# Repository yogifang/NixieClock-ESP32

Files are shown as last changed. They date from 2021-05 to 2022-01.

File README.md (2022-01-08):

# NixieClock-ESP32
Build a Clock with  Nixie Tubes 
1. MCU : ESP32-32D
2. System : Arduino 
3. Development tools : Visual Studio Code + PlatformIO + Kicad
4. Functions : Webpage Setting Wifi SSID , password & Time Zone , NTP client sync time once every day.
Watch the video

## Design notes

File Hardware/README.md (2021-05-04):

Download whole directory.
Open Project in Kicad (Ver 5.1.2-1).
ESP32-Clock is main board for 6 digits of Nixie Tubes.
Nixie is for IN-18.

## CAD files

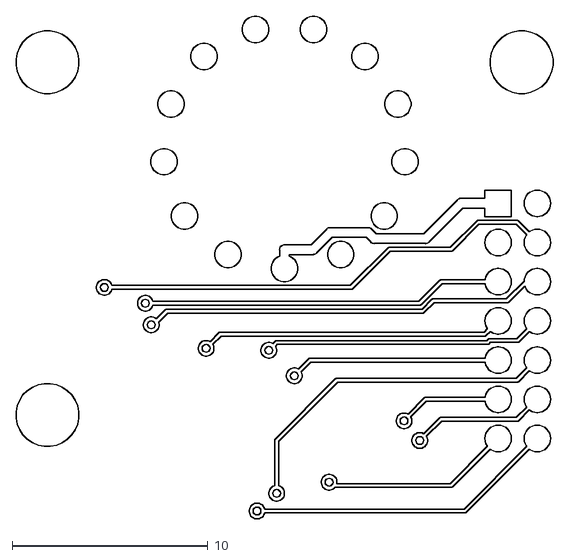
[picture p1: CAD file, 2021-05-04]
Hardware/Nixie/Nixie-B_Cu.dxf
27.4 x 25.6

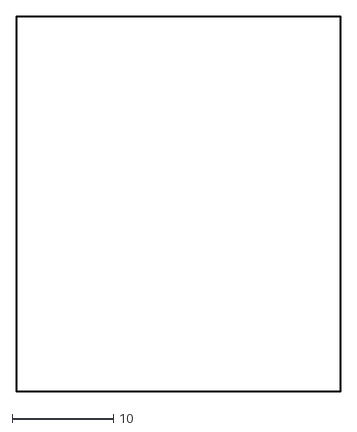
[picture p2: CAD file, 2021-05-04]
Hardware/Nixie/Nixie-Edge_Cuts.dxf
32.1 x 37.1

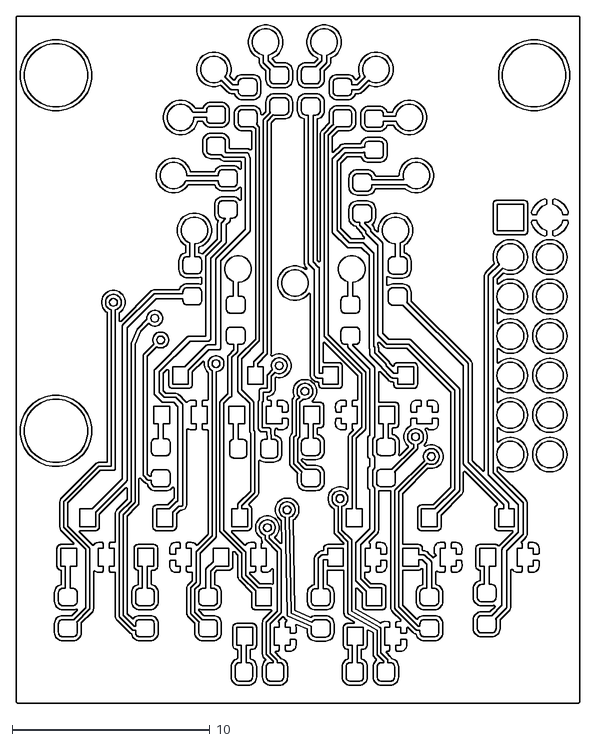
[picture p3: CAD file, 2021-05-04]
Hardware/Nixie/Nixie-F_Cu.dxf
28.5 x 34.8

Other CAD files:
Hardware/Nixie/Nixie-B_Mask.dxf
Hardware/Nixie/Nixie-B_Paste.dxf
Hardware/Nixie/Nixie-F_Mask.dxf
Hardware/Nixie/Nixie-F_Paste.dxf
Hardware/Nixie/Nixie-F_SilkS.dxf

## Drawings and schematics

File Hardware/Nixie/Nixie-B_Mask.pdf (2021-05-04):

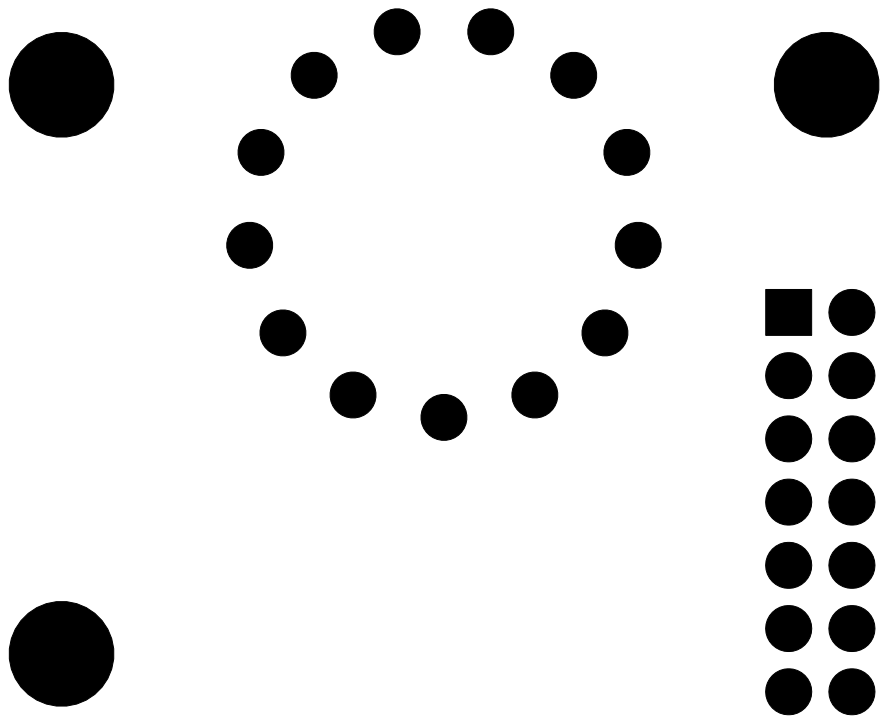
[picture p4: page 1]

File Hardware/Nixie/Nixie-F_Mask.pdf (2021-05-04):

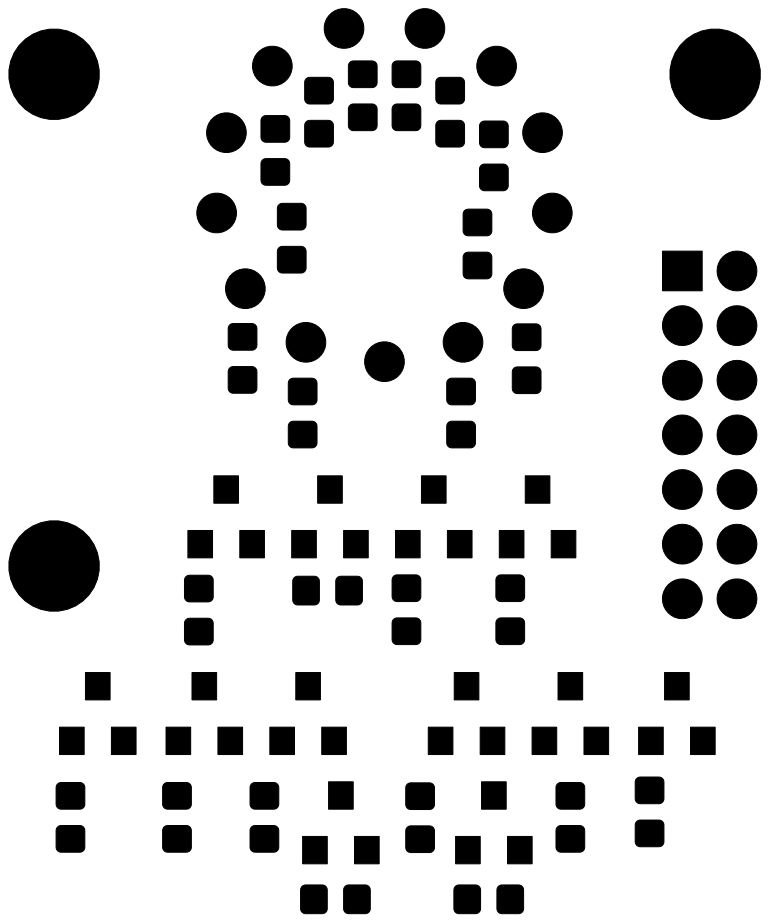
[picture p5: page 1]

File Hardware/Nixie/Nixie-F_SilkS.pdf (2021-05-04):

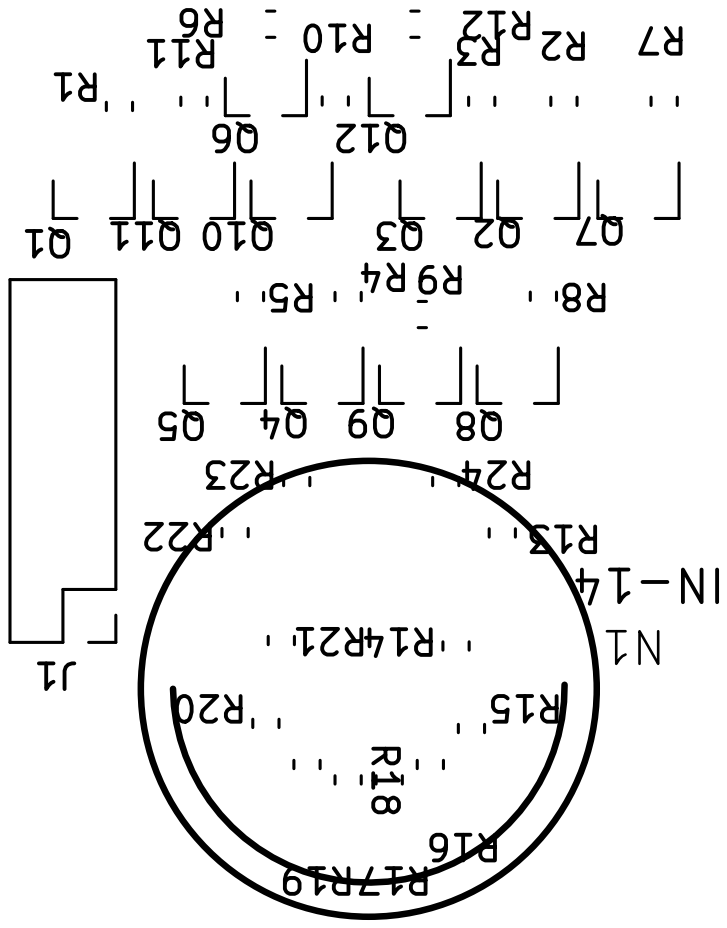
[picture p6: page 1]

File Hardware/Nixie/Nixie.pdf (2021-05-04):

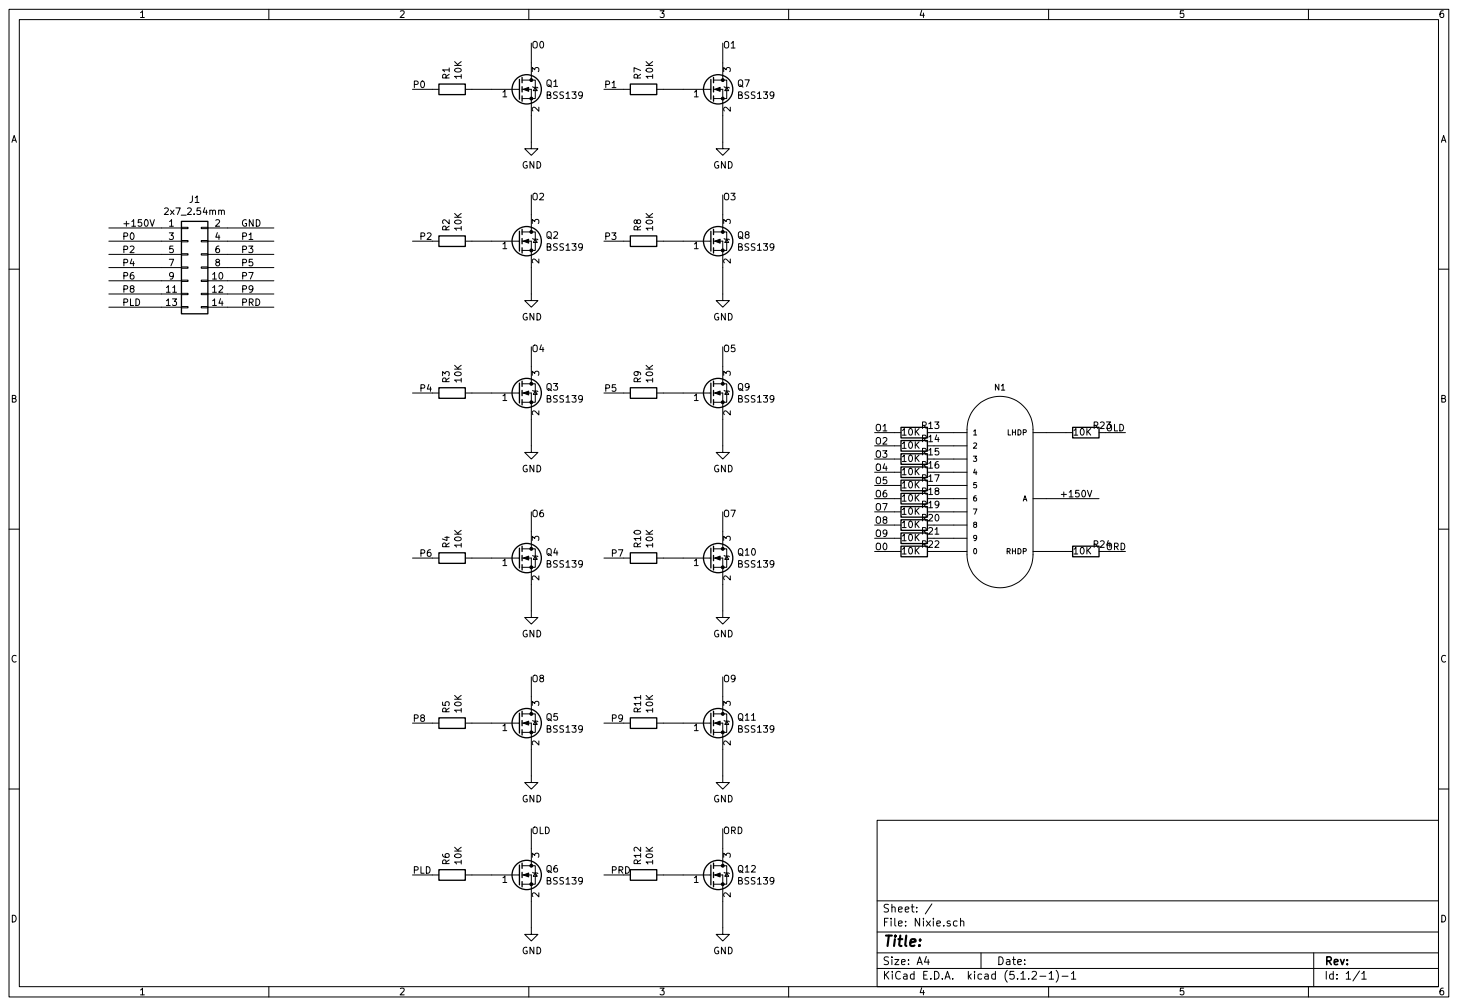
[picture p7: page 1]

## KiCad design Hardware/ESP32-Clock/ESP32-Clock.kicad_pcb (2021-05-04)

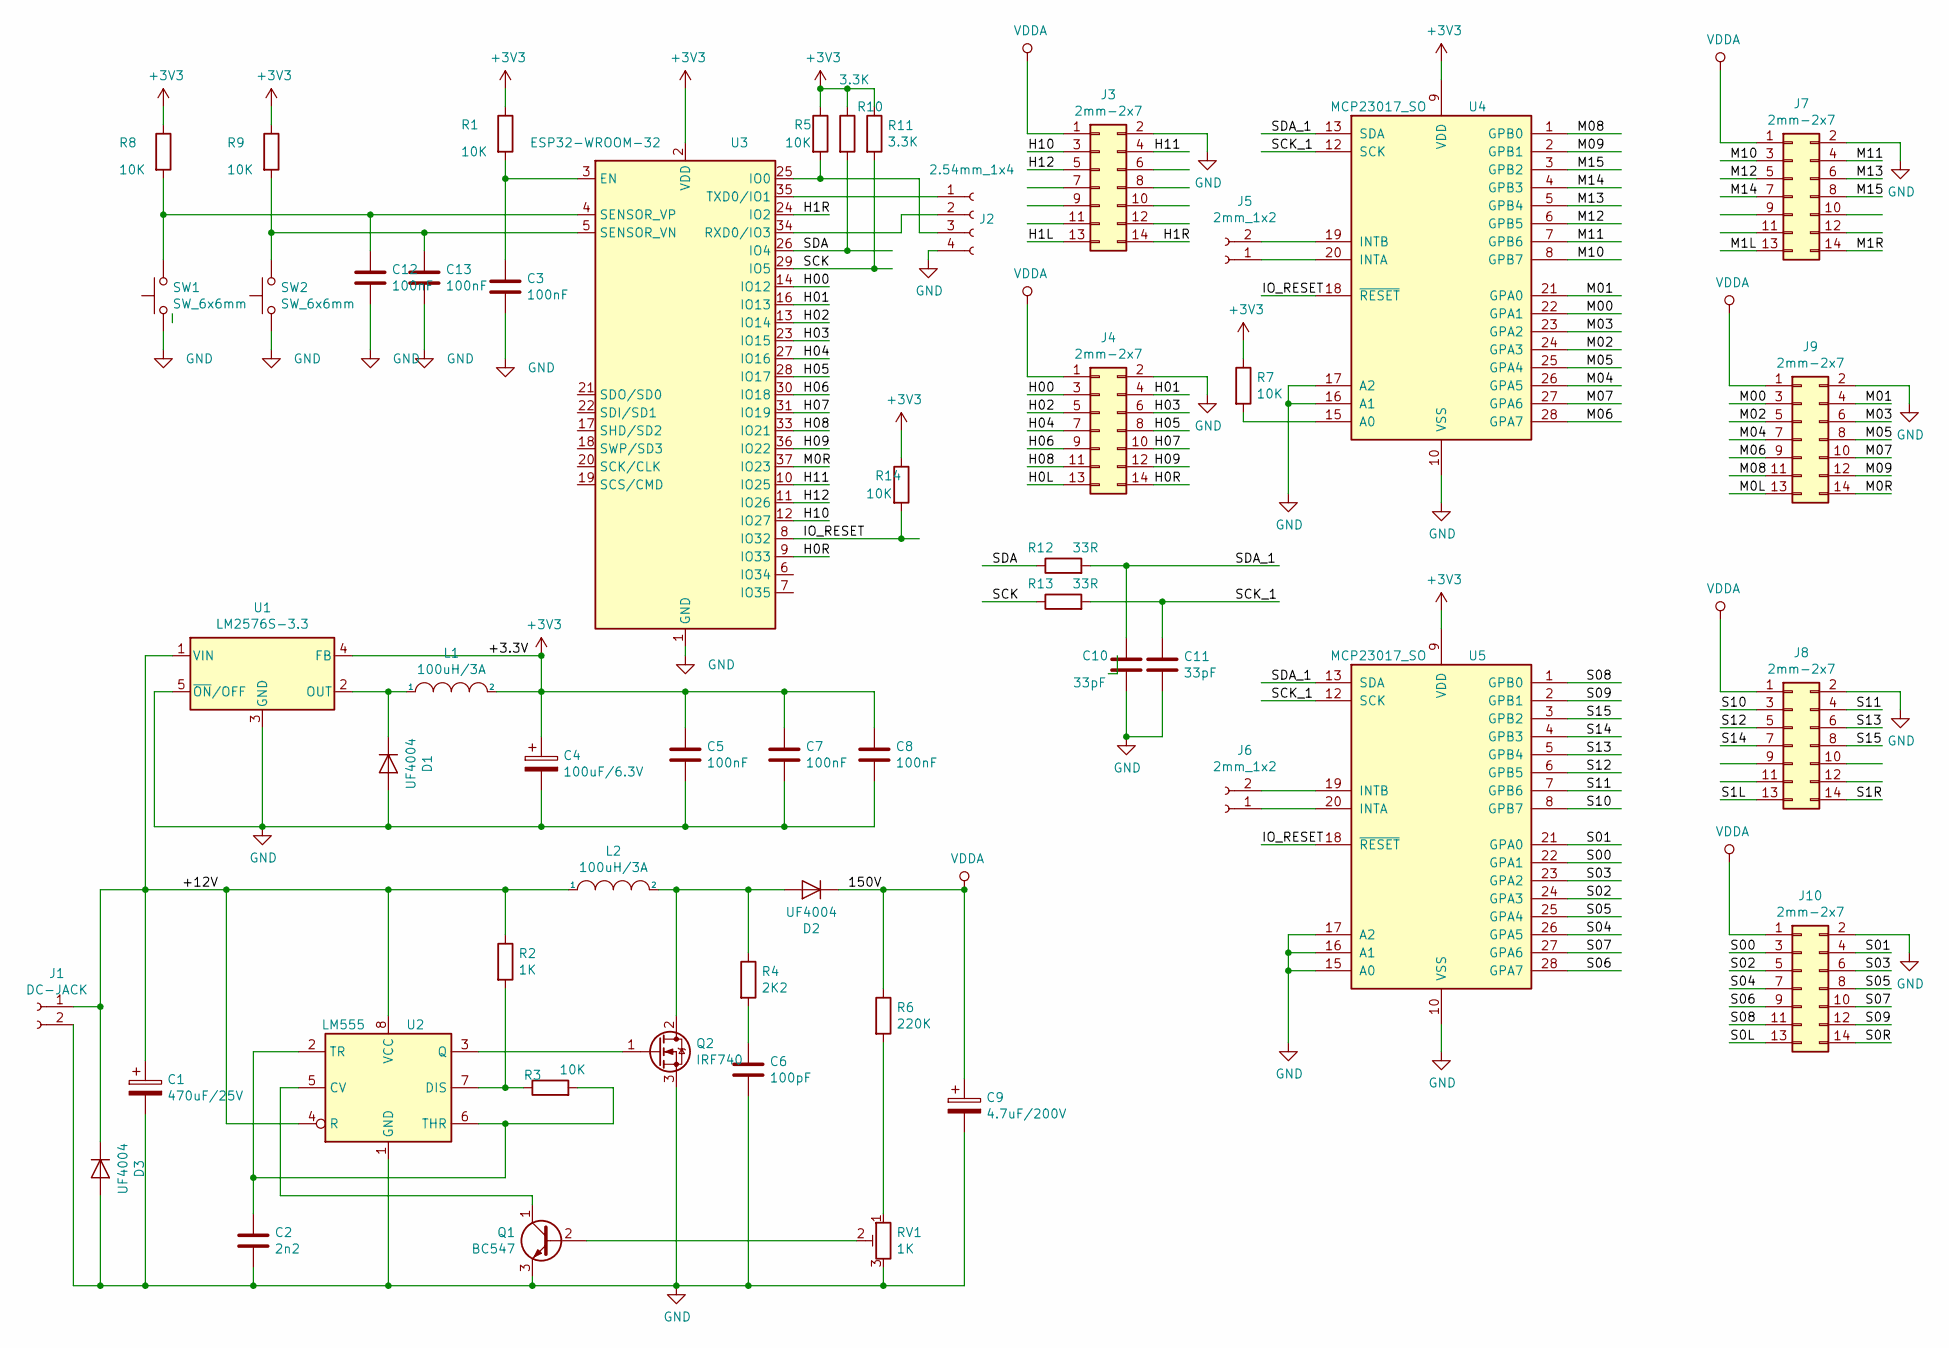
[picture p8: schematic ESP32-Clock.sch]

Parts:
C1: 470uF/25V; CP_Elec_10x10
C2: 2n2; C_0603_1608Metric
C3, C5, C7, C8, C12, C13: 100nF; C_0603_1608Metric
C4: 100uF/6.3V; CP_Elec_6.3x5.9
C6: 100pF; C_0603_1608Metric
C9: 4.7uF/200V; C_Radial_D8.0mm_H11.5mm_P3.50mm
C10, C11: 33pF; C_0603_1608Metric
D1, D2, D3: UF4004; D_SMA
J1: DC-JACK; BarrelJack_Horizontal
J2: 2.54mm_1x4; PinHeader_1x04_P2.54mm_Vertical
J3, J4, J7, J8, J9, J10: 2mm-2x7; PinHeader_2x07_P2.00mm_Vertical
J5, J6: 2mm_1x2; PinSocket_1x02_P2.00mm_Vertical
L1, L2: 100uH/3A; L_Toroid_Vertical_L13.0mm_W6.5mm_P5.60mm
Q1: BC547; TO-92_Inline
Q2: IRF740; TO-263-2
R1, R3, R5, R7, R8, R9, R14: 10K; R_0603_1608Metric
R2: 1K; R_0603_1608Metric
R4: 2K2; R_0805_2012Metric
R6: 220K; R_0805_2012Metric
R10, R11: 3.3K; R_0603_1608Metric
R12, R13: 33R; R_0603_1608Metric
RV1: 1K; Potentiometer_Bourns_3386P_Vertical
SW1, SW2: SW_6x6mm; SW_SPST_B3S-1000
U1: LM2576S-3.3; TO-263-5_TabPin3
U2: LM555; SOIC-8-1EP_3.9x4.9mm_P1.27mm_EP2.29x3mm_ThermalVias
U3: ESP32-WROOM-32
U4, U5: MCP23017_SO; SOIC-28W_7.5x17.9mm_P1.27mm

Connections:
+3V3: C4.1, C5.1, C7.1, C8.1, L1.2, R1.1, R5.1, R7.1, R8.1, R9.1, R10.1, R11.1, R14.1, U1.4 (FB), U3.2 (VDD), U4.9 (VDD), U5.9 (VDD)
/+12V: C1.1, D3.1 (K), J1.1, L2.1, R2.1, U1.1 (VIN), U2.4 (R), U2.8 (VCC)
/H00: J4.3, U3.14 (IO12)
/H0L: J4.13
/H0R: J4.14, U3.9 (IO33)
/H01: J4.4, U3.16 (IO13)
/H1L: J3.13
/H1R: J3.14, U3.24 (IO2)
/H02: J4.5, U3.13 (IO14)
/H03: J4.6, U3.23 (IO15)
/H04: J4.7, U3.27 (IO16)
/H05: J4.8, U3.28 (IO17)
/H06: J4.9, U3.30 (IO18)
/H07: J4.10, U3.31 (IO19)
/H08: J4.11, U3.33 (IO21)
/H09: J4.12, U3.36 (IO22)
/H10: J3.3, U3.12 (IO27)
/H11: J3.4, U3.10 (IO25)
/H12: J3.5, U3.11 (IO26)
/IO_RESET: R14.2, U3.8 (IO32), U4.18 (~RESET~), U5.18 (~RESET~)
/M00: J9.3, U4.22 (GPA1)
/M0L: J9.13
/M0R: J9.14, U3.37 (IO23)
/M01: J9.4, U4.21 (GPA0)
/M1L: J7.13
/M1R: J7.14
/M02: J9.5, U4.24 (GPA3)
/M03: J9.6, U4.23 (GPA2)
/M04: J9.7, U4.26 (GPA5)
/M05: J9.8, U4.25 (GPA4)
/M06: J9.9, U4.28 (GPA7)
/M07: J9.10, U4.27 (GPA6)
/M08: J9.11, U4.1 (GPB0)
/M09: J9.12, U4.2 (GPB1)
/M10: J7.3, U4.8 (GPB7)
/M11: J7.4, U4.7 (GPB6)
/M12: J7.5, U4.6 (GPB5)
/M13: J7.6, U4.5 (GPB4)
/M14: J7.7, U4.4 (GPB3)
/M15: J7.8, U4.3 (GPB2)
/S00: J10.3, U5.22 (GPA1)
/S0L: J10.13
/S0R: J10.14
/S01: J10.4, U5.21 (GPA0)
/S1L: J8.13
/S1R: J8.14
/S02: J10.5, U5.24 (GPA3)
/S03: J10.6, U5.23 (GPA2)
/S04: J10.7, U5.26 (GPA5)
/S05: J10.8, U5.25 (GPA4)
/S06: J10.9, U5.28 (GPA7)
/S07: J10.10, U5.27 (GPA6)
/S08: J10.11, U5.1 (GPB0)
/S09: J10.12, U5.2 (GPB1)
/S10: J8.3, U5.8 (GPB7)
/S11: J8.4, U5.7 (GPB6)
/S12: J8.5, U5.6 (GPB5)
/S13: J8.6, U5.5 (GPB4)
/S14: J8.7, U5.4 (GPB3)
/S15: J8.8, U5.3 (GPB2)
/SCK: R11.2, R13.1, U3.29 (IO5)
/SCK_1: C11.1, R13.2, U4.12 (SCK), U5.12 (SCK)
/SDA: R10.2, R12.1, U3.26 (IO4)
/SDA_1: C10.1, R12.2, U4.13 (SDA), U5.13 (SDA)
GND: C1.2, C2.2, C3.2, C4.2, C5.2, C6.2, C7.2, C8.2, C9.2, C10.2, C11.2, C12.2, C13.2, D1.2 (A), D3.2 (A), J1.2, J2.4, J3.2, J4.2, J7.2, J8.2, J9.2, J10.2, Q1.3 (E), Q2.3 (S), RV1.3, SW1.2, SW2.2, U1.3 (GND), U1.5 (~ON~/OFF), U2.1 (GND), U3.1 (GND), U3.15 (GND), U3.38 (GND), U4.10 (VSS), U4.16 (A1), U4.17 (A2), U5.10 (VSS), U5.15 (A0), U5.16 (A1), U5.17 (A2)
unnamed: C2.1, R3.2, U2.2 (TR), U2.6 (THR)
unnamed: C3.1, R1.2, U3.3 (EN)
unnamed: C6.1, R4.2
unnamed: C12.1, R8.2, SW1.1, U3.4 (SENSOR_VP)
unnamed: C13.1, R9.2, SW2.1, U3.5 (SENSOR_VN)
unnamed: D1.1 (K), L1.1, U1.2 (OUT)
unnamed: D2.2 (A), L2.2, Q2.2 (D), R4.1
unnamed: J2.1, U3.35 (TXD0/IO1)
unnamed: J2.2, U3.34 (RXD0/IO3)
unnamed: J2.3, R5.2, U3.25 (IO0)
unnamed: J5.1, U4.20 (INTA)
unnamed: J5.2, U4.19 (INTB)
unnamed: J6.1, U5.20 (INTA)
unnamed: J6.2, U5.19 (INTB)
unnamed: Q1.1 (C), U2.5 (CV)
unnamed: Q1.2 (B), RV1.2
unnamed: Q2.1 (G), U2.3 (Q)
unnamed: R2.2, R3.1, U2.7 (DIS)
unnamed: R6.2, RV1.1
unnamed: R7.2, U4.15 (A0)
VDDA: C9.1, D2.1 (K), J3.1, J4.1, J7.1, J8.1, J9.1, J10.1, R6.1

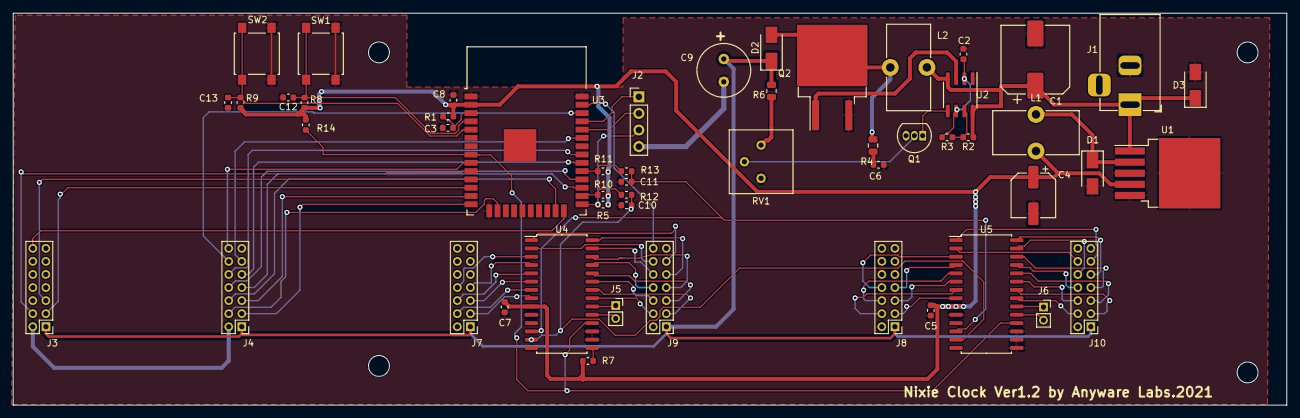
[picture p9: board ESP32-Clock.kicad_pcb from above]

Board: 2 copper layers, 195.0 x 60.0 mm, 52 parts (0 on the bottom side), 77 nets.

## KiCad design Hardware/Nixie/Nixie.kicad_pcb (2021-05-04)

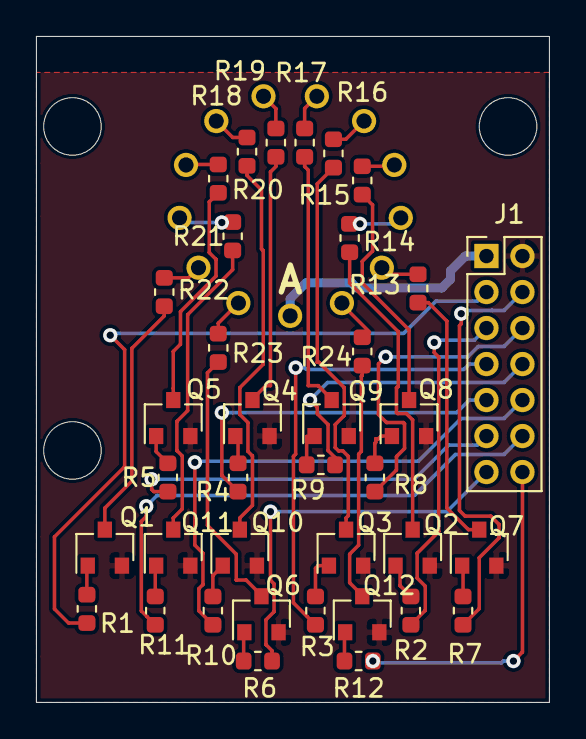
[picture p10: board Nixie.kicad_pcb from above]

Board: 2 copper layers, 28.5 x 37.0 mm, 38 parts (1 on the bottom side), 50 nets.

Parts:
J1: 2x7_2.54mm; PinHeader_2x07_P2.00mm_Vertical
N1: IN-14; nixies-us-IN-14
Q1, Q2, Q3, Q4, Q5, Q6, Q7, Q8, Q9, Q10, Q11, Q12: BSS139; SOT-23
R1, R2, R3, R4, R5, R6, R7, R8, R9, R10, R11, R12, R13, R14, R15, R16, R17, R18, R19, R20, R21, R22, R23, R24: 10K; R_0603_1608Metric

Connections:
/+150V: J1.1, N1.A
/O0: Q1.3, R22.1
/O1: Q7.3, R13.1
/O2: Q2.3, R14.1
/O3: Q8.3, R15.1
/O4: Q3.3, R16.1
/O5: Q9.3, R17.1
/O6: Q4.3, R18.1
/O7: Q10.3, R19.1
/O8: Q5.3, R20.1
/O9: Q11.3, R21.1
/OLD: Q6.3, R23.2
/ORD: Q12.3, R24.2
/P0: J1.3, R1.1
/P1: J1.4, R7.1
/P2: J1.5, R2.1
/P3: J1.6, R8.1
/P4: J1.7, R3.1
/P5: J1.8, R9.1
/P6: J1.9, R4.1
/P7: J1.10, R10.1
/P8: J1.11, R5.1
/P9: J1.12, R11.1
/PLD: J1.13, R6.1
/PRD: J1.14, R12.1
GND: J1.2, Q1.2, Q2.2, Q3.2, Q4.2, Q5.2, Q6.2, Q7.2, Q8.2, Q9.2, Q10.2, Q11.2, Q12.2
unnamed: N1.0, R22.2
unnamed: N1.1, R13.2
unnamed: N1.2, R14.2
unnamed: N1.3, R15.2
unnamed: N1.4, R16.2
unnamed: N1.5, R17.2
unnamed: N1.6, R18.2
unnamed: N1.7, R19.2
unnamed: N1.8, R20.2
unnamed: N1.9, R21.2
unnamed: N1.LHDP, R23.1
unnamed: N1.RHDP, R24.1
unnamed: Q1.1, R1.2
unnamed: Q2.1, R2.2
unnamed: Q3.1, R3.2
unnamed: Q4.1, R4.2
unnamed: Q5.1, R5.2
unnamed: Q6.1, R6.2
unnamed: Q7.1, R7.2
unnamed: Q8.1, R8.2
unnamed: Q9.1, R9.2
unnamed: Q10.1, R10.2
unnamed: Q11.1, R11.2
unnamed: Q12.1, R12.2

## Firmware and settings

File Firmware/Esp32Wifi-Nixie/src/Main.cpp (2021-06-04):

/*
    WifiSettings basic example

    Source and further documentation available at
    https://github.com/Juerd/ESP-WiFiSettings

    Note: this example is written for ESP32.
    For ESP8266, use LittleFS.begin() instead of SPIFFS.begin(true).
*/

#include "Adafruit_MCP23017.h"
#include <Arduino.h>
#include <NTPClient.h>
#include <SPIFFS.h>
#include <WiFiSettings.h>
#include <WiFiUdp.h>
#include <Wire.h>
void dspMinSec(bool bMin , byte byTime);


#define NEW_BOARD  1

#define  NIXIE_IN14  1
//#define  NIXIE_IN8   1


#define MCPAddr1 0x20
#define MCPAddr2 0x21

#define I2C_SDA 4
#define I2C_SCL 5

WiFiUDP ntpUDP;
NTPClient timeClient(ntpUDP);
String formattedDate;
String dayStamp;
String timeStamp;

Adafruit_MCP23017 mcpSec;
Adafruit_MCP23017 mcpMin;
volatile int interruptCounter;
int totalInterruptCounter;

hw_timer_t *timer = NULL;
portMUX_TYPE timerMux = portMUX_INITIALIZER_UNLOCKED;

bool bForceResetMcp = false;
bool bTimeFlish = false;
bool bSecChanged = true;
bool bMinChanged = true;
bool bHourChanged = true;
int iCnt = 0;
int iSec = 0;
int iMin = 0;
int iHour = 0;

const int iI2CRESET = 32;

const int iSW1 = 36;
const int iSW2 = 39;
int iCntSW1 = 0 ;
int iCntSW2 = 0 ;


#ifdef NEW_BOARD 
const int iH10 = 27;
const int iH11 = 25;
const int iH12 = 26;
const int iH1R = 34;
#endif
#ifndef NEW_BOARD
const int iH10 = 23;
const int iH11 = 25;
const int iH12 = 26;
const int iH1R = 34;
#endif

const int iH00 = 12;
const int iH01 = 13;
const int iH02 = 14;
const int iH03 = 15;
const int iH04 = 16;
const int iH05 = 17;
const int iH06 = 18;
const int iH07 = 19;
const int iH08 = 21;
const int iH09 = 22;
const int iH0R = 33;


#ifdef NIXIE_IN14 
const int iH1[] = {iH10, iH11, iH12, iH1R};

const int iH0[] = {iH00, iH01, iH02, iH03, iH04, iH05,
                   iH06, iH07, iH08, iH09, iH0R};

const uint16_t iMS0[10] = {BIT1, BIT0, BIT3, BIT2, BIT5,
                           BIT4, BIT7, BIT6, BIT8, BIT9};
const uint16_t iMS1[6] = {BIT15, BIT14, BIT13, BIT12, BIT11, BIT10};
#endif

#ifdef NIXIE_IN8
const int iH1[] = {iH10, iH11, iH12, iH1R};

const int iH0[] = {iH00, iH01, iH02, iH03, iH04, iH05,
                   iH06, iH07, iH08, iH09, iH0R};

const uint16_t iMS0[10] = {BIT8, BIT9, BIT1, BIT7, BIT4,
                           BIT5, BIT2, BIT3, BIT1, BIT2};
const uint16_t iMS1[6] = {BIT15, BIT14, BIT13, BIT12, BIT11, BIT10};
#endif



void IRAM_ATTR onTimer() {
  portENTER_CRITICAL_ISR(&timerMux);
  interruptCounter++;
  if (bTimeFlish == true) {
    iSec++;
    bSecChanged = true;
    if (iSec > 59) {
      iSec = 0;
      iMin++;
      bMinChanged = true;
      if (iMin > 59) {
        iMin = 0;
        iHour++;
        bHourChanged = true;
        if (iHour > 23)
          iHour = 0;
      }
    }
  }

  portEXIT_CRITICAL_ISR(&timerMux);
}

void initMcp23017() {
  digitalWrite(iI2CRESET, LOW);
  delay(1);
  digitalWrite(iI2CRESET, HIGH);

  mcpSec.begin(0x0, &Wire); // use default address 0
  mcpMin.begin(0x1, &Wire);

  Wire.beginTransmission(MCPAddr1);
  Wire.write(0x00); // address port A direction
  Wire.write(0x00); // value to send
  Wire.endTransmission();
  Wire.beginTransmission(MCPAddr1);
  Wire.write(0x01); // address port B direction
  Wire.write(0x00); // value to send output
  Wire.endTransmission();
  Wire.beginTransmission(MCPAddr2);
  Wire.write(0x00); // address port A direction
  Wire.write(0x00); // value to send
  Wire.endTransmission();
  Wire.beginTransmission(MCPAddr2);
  Wire.write(0x01); // address port B direction
  Wire.write(0x00); // value to send output
  Wire.endTransmission();

  mcpSec.writeGPIOAB(0x0000);
  mcpMin.writeGPIOAB(0x0000);
}

void setup() {
  Serial.begin(115200);
   Serial.println("Nixie Clock Controller Ver1.5");

   Wire.begin(I2C_SDA, I2C_SCL, 400000); // wake up I2C bus

  pinMode(iI2CRESET, OUTPUT);
  pinMode(iSW1, INPUT_PULLUP);
  pinMode(iSW2, INPUT_PULLUP);

  for (iCnt = 0; iCnt < sizeof(iH1) / 4; iCnt++) {
    pinMode(iH1[iCnt], OUTPUT);
    digitalWrite(iH1[iCnt], LOW);
  }

  for (iCnt = 0; iCnt < sizeof(iH0) / 4; iCnt++) {
    pinMode(iH0[iCnt], OUTPUT);
    digitalWrite(iH0[iCnt], LOW);
  }
  initMcp23017();
  
  bSecChanged = true ;
  dspMinSec(false , 0) ;

   SPIFFS.begin(true); // Will format on the first run after failing to mount
   delay(500) ;
  // Use stored credentials to connect to your WiFi access point.
  // If no credentials are stored or if the access point is out of reach,
  // an access point will be started with a captive portal to configure WiFi.
  bSecChanged = true ;
  dspMinSec(false , 1) ;
  WiFiSettings.connect();

  String strTZ = WiFiSettings.timezone ;
  int iOffset = 0 ;
  if(strTZ.length() > 0) {
   iOffset = 3600 * strTZ.toInt() ;
  }
  
  timeClient.begin();
  // Set offset time in seconds to adjust for your timezone, for example:
  // GMT +1 = 3600
  // GMT +8 = 28800
  // GMT -1 = -3600
  // GMT 0 = 0
  timeClient.setTimeOffset(iOffset);

 
 
  // set I/O pins to outputs

  Serial.println("MCP init.........");
  interrupts();
  timer = timerBegin(0, 80, true);
  timerAttachInterrupt(timer, &onTimer, true);
  // timerAlarmWrite(timer, 1000000, true);
  timerAlarmWrite(timer, 1000000, true);
  timerAlarmEnable(timer);
}
//================================================================================================


void dspMinSec(bool bMin, byte byTime) {
  Adafruit_MCP23017 *pMcp;
  if (bMin == true) {
    if (bMinChanged == false)
      return;
    pMcp = &mcpMin;
    bMinChanged = false;
    // Serial.print("Min.........");
  } else {
    if (bSecChanged == false)
      return;
    pMcp = &mcpSec;
    bSecChanged = false;
    // Serial.print("Sec.........");
  }

  byte by10 = byTime / 10;
  byte by0 = byTime % 10;
  // Serial.println("dspMinSec ........");
  uint16_t u16Data = 0;
  u16Data = iMS0[by0] | iMS1[by10];
  //u16Data = BIT10 ;
  noInterrupts();

   
  pMcp->writeGPIOAB(u16Data);
  if (u16Data != pMcp->readGPIOAB()) {
    bForceResetMcp = true;
    bMinChanged = true;
    bSecChanged = true;
  }
  interrupts();
}


void dspHour(byte byTime) {

  if (bHourChanged == false)
    return;
  if (byTime > 24)
    byTime = 0;

  byte by10 = byTime / 10;
  byte by0 = byTime % 10;

  for (iCnt = 0; iCnt < sizeof(iH1) / 4; iCnt++) {
    pinMode(iH1[iCnt], OUTPUT);
    digitalWrite(iH1[iCnt], LOW);
  }

  for (iCnt = 0; iCnt < sizeof(iH0) / 4; iCnt++) {
    pinMode(iH0[iCnt], OUTPUT);
    digitalWrite(iH0[iCnt], LOW);
  }

  digitalWrite(iH0[by0], HIGH);
  digitalWrite(iH1[by10], HIGH);
  bHourChanged = false;
}
void getInternetTime() {

  while (!timeClient.update()) {
    timeClient.forceUpdate();
  }
  // initMcp23017();
  // The formattedDate comes with the following format:
  // 2018-05-28T16:00:13Z
  // We need to extract date and time
  formattedDate = timeClient.getFormattedDate();
  // Serial.println(formattedDate);

  // Extract date
  int splitT = formattedDate.indexOf("T");
  // dayStamp = formattedDate.substring(0, splitT);
  // Serial.print("DATE: ");
  // Serial.println(dayStamp);
  // Extract time
  timeStamp = formattedDate.substring(splitT + 1, formattedDate.length() - 1);
  sscanf(timeStamp.c_str(), "%d:%d:%d", &iHour, &iMin, &iSec);
  Serial.print("HOUR: ");
  Serial.println(timeStamp);
  bMinChanged = true;
  bSecChanged = true;
  bHourChanged = true;
  dspMinSec(false, (byte)iSec);
  dspMinSec(true, (byte)iMin);
  dspHour((byte)iHour);
  delay(900);
}
//================================================================================================
void loop() {


  if (interruptCounter > 0) {
    portENTER_CRITICAL(&timerMux);
    interruptCounter--;
    portEXIT_CRITICAL(&timerMux);
    dspMinSec(false, (byte)iSec);
    dspMinSec(true, (byte)iMin);
    dspHour((byte)iHour);
    return;
  }
  if (bForceResetMcp == true) {
    initMcp23017();
    bForceResetMcp = false;
    bSecChanged = true;
    bMinChanged = true;
    bHourChanged = true;
    dspMinSec(false, (byte)iSec);
    dspMinSec(true, (byte)iMin);
    dspHour((byte)iHour);
  }

  int iZeroTime = iHour + iMin + iSec;
  if (iZeroTime == 0)
    bTimeFlish = false;

  if (bTimeFlish == false) {
    getInternetTime();
    bTimeFlish = true;
  }
  if (digitalRead(iSW1) == false) {
    iCntSW1++ ;
    if(iCntSW1 > 10000) {
      Serial.println("Switch 1 pressed.......") ;
      iCntSW1 = 10000 ;
      while (digitalRead(iSW1) != true) {
          iCntSW1 = 0 ;
      };
      WiFiSettings.portal() ;
    }
  } else {
    iCntSW1 = 0 ;
  }
}

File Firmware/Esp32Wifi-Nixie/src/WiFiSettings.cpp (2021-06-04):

#include "WiFiSettings.h"
#ifdef ESP32
#define ESPFS SPIFFS
#define ESPMAC (Sprintf("%06" PRIx64, ESP.getEfuseMac() >> 24))
#include <SPIFFS.h>
#include <WebServer.h>
#include <WiFi.h>
#include <esp_task_wdt.h>
#elif ESP8266
#define ESPFS LittleFS
#define ESPMAC (Sprintf("%06" PRIx32, ESP.getChipId()))
#include <ESP8266WebServer.h>
#include <ESP8266WiFi.h>
#include <LittleFS.h>
#define WebServer ESP8266WebServer
#define esp_task_wdt_reset wdt_reset
#define wifi_auth_mode_t uint8_t // wl_enc_type
#define WIFI_AUTH_OPEN ENC_TYPE_NONE
constexpr auto WIFI_AUTH_WPA2_ENTERPRISE = -1337; // not available on ESP8266
#define setHostname hostname
#define INADDR_NONE IPAddress(0, 0, 0, 0)
#else
#error "This library only supports ESP32 and ESP8266"
#endif
#include <DNSServer.h>
#include <WiFiSettings_strings.h>
#include <limits.h>
#include <vector>

WiFiSettingsLanguage::Texts _WSL_T;

#define Sprintf(f, ...)                                                        \
  ({                                                                           \
    char *s;                                                                   \
    asprintf(&s, f, __VA_ARGS__);                                              \
    String r = s;                                                              \
    free(s);                                                                   \
    r;                                                                         \
  })

namespace { // Helpers
String slurp(const String &fn) {
  File f = ESPFS.open(fn, "r");
  String r = f.readString();
  f.close();
  return r;
}

bool spurt(const String &fn, const String &content) {
  File f = ESPFS.open(fn, "w");
  if (!f)
    return false;
  auto w = f.print(content);
  f.close();
  return w == content.length();
}

String pwgen() {
 // const char *passchars = "ABCEFGHJKLMNPRSTUXYZabcdefhkmnorstvxz23456789-#@?!";
  String password = "12345678";
  for (int i = 0; i < 16; i++) {
    // Note: no seed needed for ESP8266 and ESP32 hardware RNG
   // password.concat(passchars[random(strlen(passchars))]);

  }
  
  return password;
}

String html_entities(const String &raw) {
  String r;
  for (unsigned int i = 0; i < raw.length(); i++) {
    char c = raw.charAt(i);
    if (c < '!' || c == '"' || c == '&' || c == '\'' || c == '<' || c == '>' ||
        c == 0x7f) {
      // ascii control characters, html syntax characters, and space
      r += Sprintf("&#%d;", c);
    } else {
      r += c;
    }
  }
  return r;
}

struct WiFiSettingsParameter {
  String name;
  String label;
  String value;
  String init;
  long min = LONG_MIN;
  long max = LONG_MAX;

  String filename() {
    String fn = "/";
    fn += name;
    return fn;
  }
  bool store() {
    return (name && name.length()) ? spurt(filename(), value) : true;
  }
  void fill() {
    if (name && name.length())
      value = slurp(filename());
  }
  virtual void set(const String &) = 0;
  virtual String html() = 0;
};

struct WiFiSettingsString : WiFiSettingsParameter {
  virtual void set(const String &v) { value = v; }
  String html() {
    String h =
        F("<p><label>{label}:<br><input style='font-size:100%' name='{name}' value='{value}' "
          "placeholder='{init}' minlength={min} maxlength={max}></label>");
    h.replace("{name}", html_entities(name));
    h.replace("{value}", html_entities(value));
    h.replace("{init}", html_entities(init));
    h.replace("{label}", html_entities(label));
    h.replace("{min}", String(min));
    h.replace("{max}", String(max));
    return h;
  }
};

struct WiFiSettingsInt : WiFiSettingsParameter {
  virtual void set(const String &v) { value = v; }
  String html() {
    String h =
        F("<p><label>{label}:<br><input type=number step=1 min={min} max={max} "
          "name='{name}' value='{value}' placeholder='{init}'></label>");
    h.replace("{name}", html_entities(name));
    h.replace("{value}", html_entities(value));
    h.replace("{init}", html_entities(init));
    h.replace("{label}", html_entities(label));
    h.replace("{min}", String(min));
    h.replace("{max}", String(max));
    return h;
  }
};

struct WiFiSettingsBool : WiFiSettingsParameter {
  virtual void set(const String &v) { value = v.length() ? "1" : "0"; }
  String html() {
    String h = F("<p><label class=c><input type=checkbox name='{name}' "
                 "value=1{checked}> {label} ({default}: {init})</label>");
    h.replace("{name}", html_entities(name));
    h.replace("{default}", _WSL_T.init);
    h.replace("{checked}", value.toInt() ? " checked" : "");
    h.replace("{init}", init.toInt() ? "&#x2611;" : "&#x2610;");
    h.replace("{label}", html_entities(label));
    return h;
  }
};
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
